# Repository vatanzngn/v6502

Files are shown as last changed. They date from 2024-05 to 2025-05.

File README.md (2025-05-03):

# 💻 vz6502: A Homebrew Single Board Computer Based on WDC 65C02

A custom-built single board computer (SBC) powered by the WDC 65C02 processor, featuring VGA and PS/2 interfaces, an onboard terminal, and a CPLD-based system controller.

---

## ⚙️ Specifications

- **CPU:** WDC 65C02 @ 1.8432 MHz (chosen for UART-compatible clock rate)
- **System Controller:** Altera EPM7128SLC84 CPLD
- **ROM:** Atmel 28C256 EEPROM (16 KB used)
- **RAM:** Hitachi 62256 SRAM (28 KB used)
- **Serial Interfaces:**  
  - 2× 65C51 ACIA (UART and terminal communication)
- **I/O Interface:**  
  - 1× 65C22 VIA
- **Video Output:** VGA interface  
- **Input:** PS/2 keyboard  
- **Terminal:** Atmega328P-based serial terminal

## 🧩 PCB Design

<div align="center">
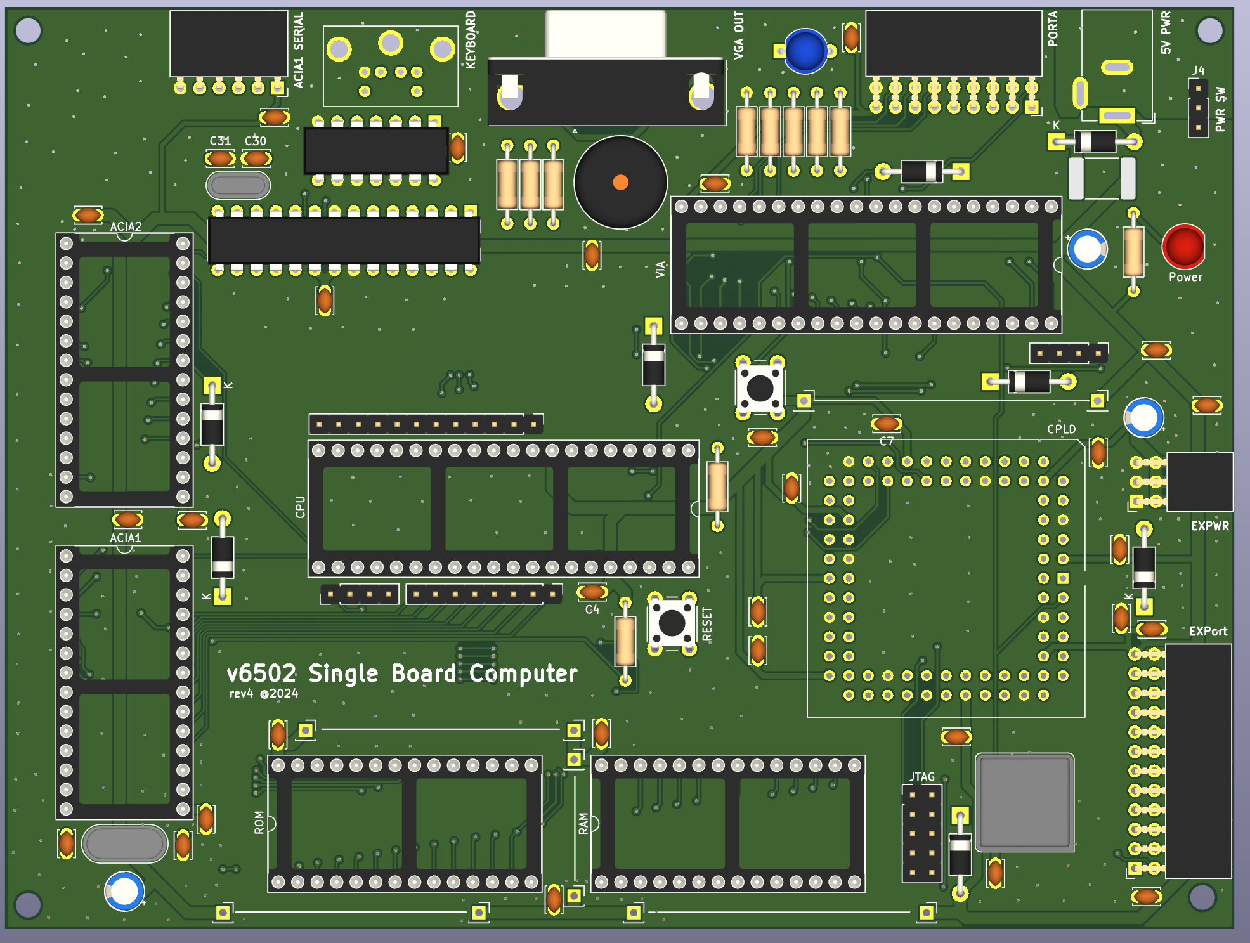
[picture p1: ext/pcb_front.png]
Front side of PCB
  
  <p><em>Front side of the PCB</em></p>
</div>

<div align="center">
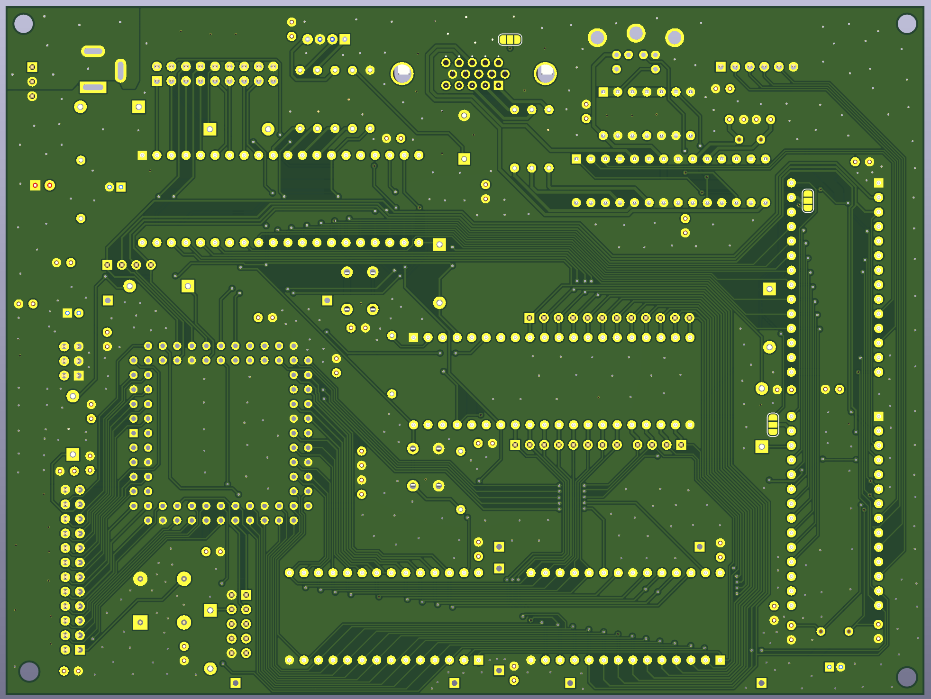
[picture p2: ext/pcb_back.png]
Back side of PCB
  
  <p><em>Back side of the PCB</em></p>
</div>

## 🔌 Schematic

<div align="center">
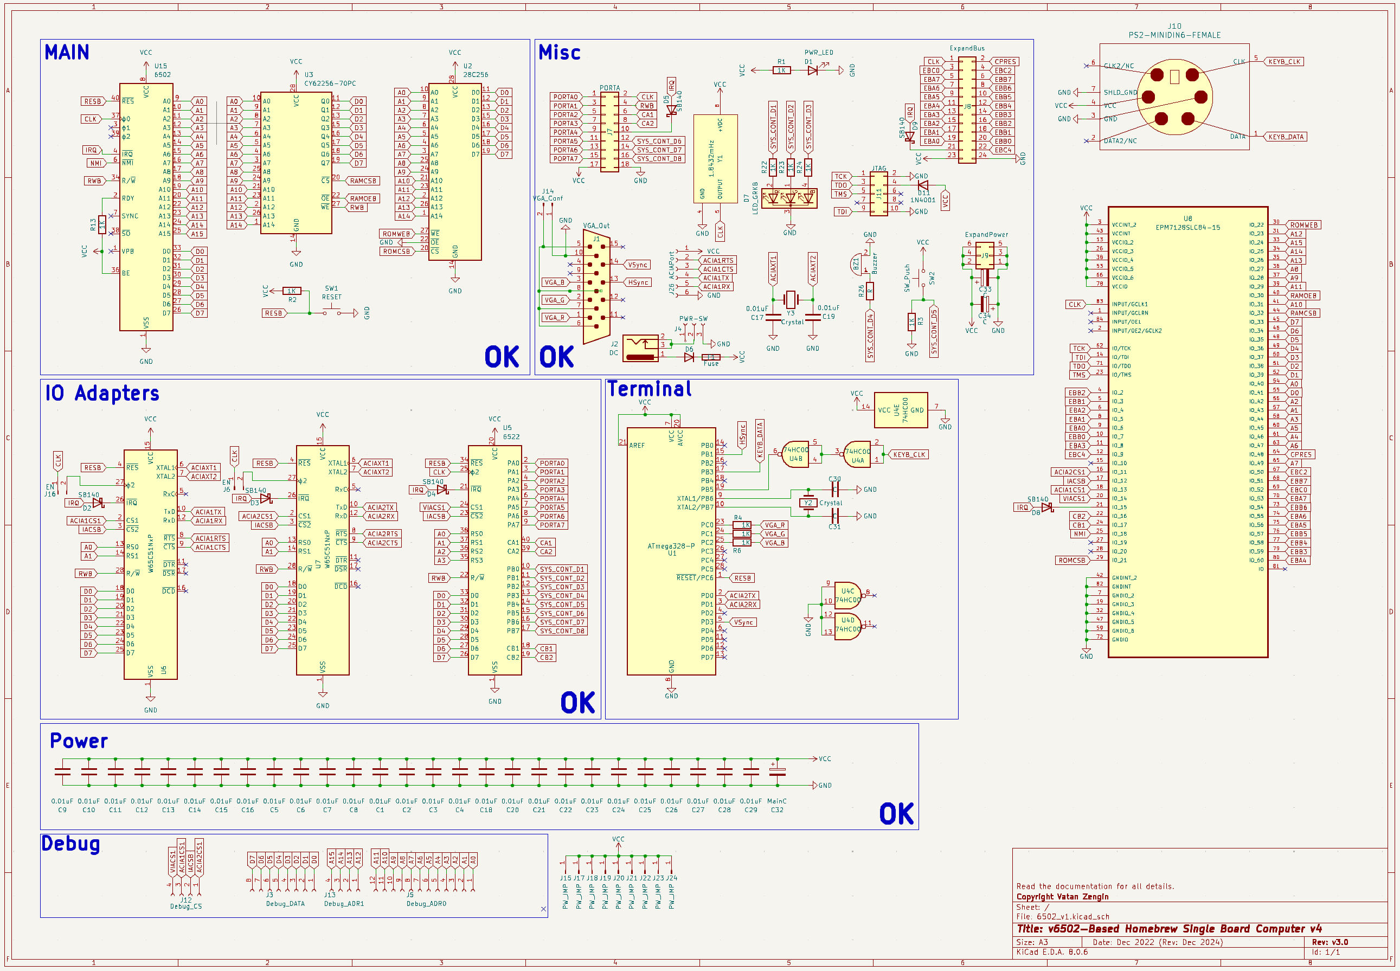
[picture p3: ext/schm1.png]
Schematic Diagram
  
  <p><em>System schematic showing CPU, RAM, ROM, I/O, and video interfaces</em></p>
</div>

## 🧠 Memory Map Overview

### 📋 Detailed Address Mapping

| Unit | First Address (bin) | Last Address (bin) | Address Range (Hex) | Description | Size  |
|---|---|---|---|---|---|
| RAM | 0000 0000 0000 0000 | 0110 1111 1111 1111 | 0000–6FFF | System memory | 28 KB |
| VIA0 | 0111 0000 0000 0000 | 0111 0000 0000 1100 | 7000–700C | VIA 0 registers | 12 B  |
| VIA1 | 0111 0001 0000 0000 | 0111 0001 0000 1100 | 7100–710C | VIA 1 registers | 12 B  |
| ACIA0  | 0111 0010 0000 0000 | 0111 0010 0000 0011 | 7200–7203 | ACIA 0 registers | 4 B |
| ACIA1  | 0111 0011 0000 0000 | 0111 0011 0000 0011 | 7300–7303 | ACIA 1 registers | 4 B |
| RESRV  | 0111 0100 0000 0000 | 0111 1111 1111 1111 | 7304–7FFF | Reserved | N/A |
| ROM | 1000 0000 0000 0000 | 1111 1111 1111 1111 | 8000–FFFF | System ROM | 32 KB |

---

## 📁 File Structure

| Folder | Description |
|---|---|
| `/pcb` | KiCAD PCB design files |
| `/gerber`| Gerber files for PCB manufacturing |
| `/ext` | GitHub assets, images, and extras  |

---
⚠️ CPLD and operating system source files will be uploaded in a future update.

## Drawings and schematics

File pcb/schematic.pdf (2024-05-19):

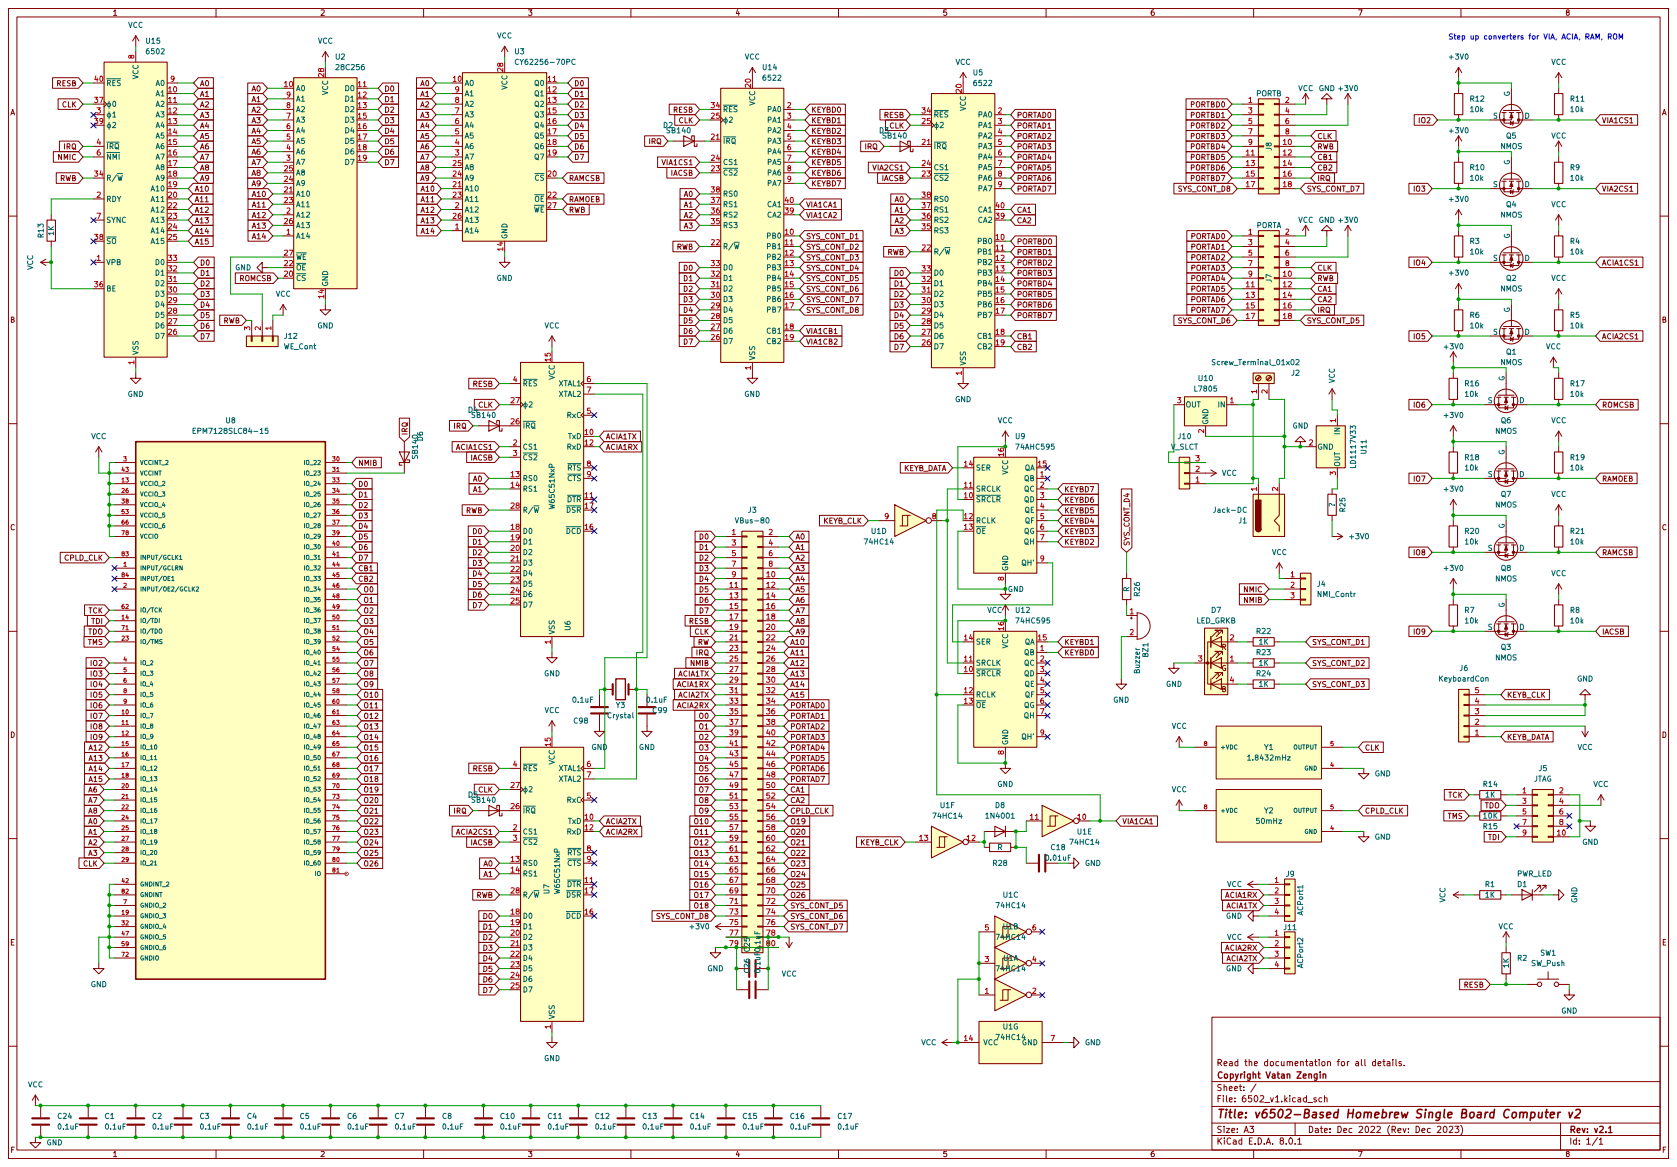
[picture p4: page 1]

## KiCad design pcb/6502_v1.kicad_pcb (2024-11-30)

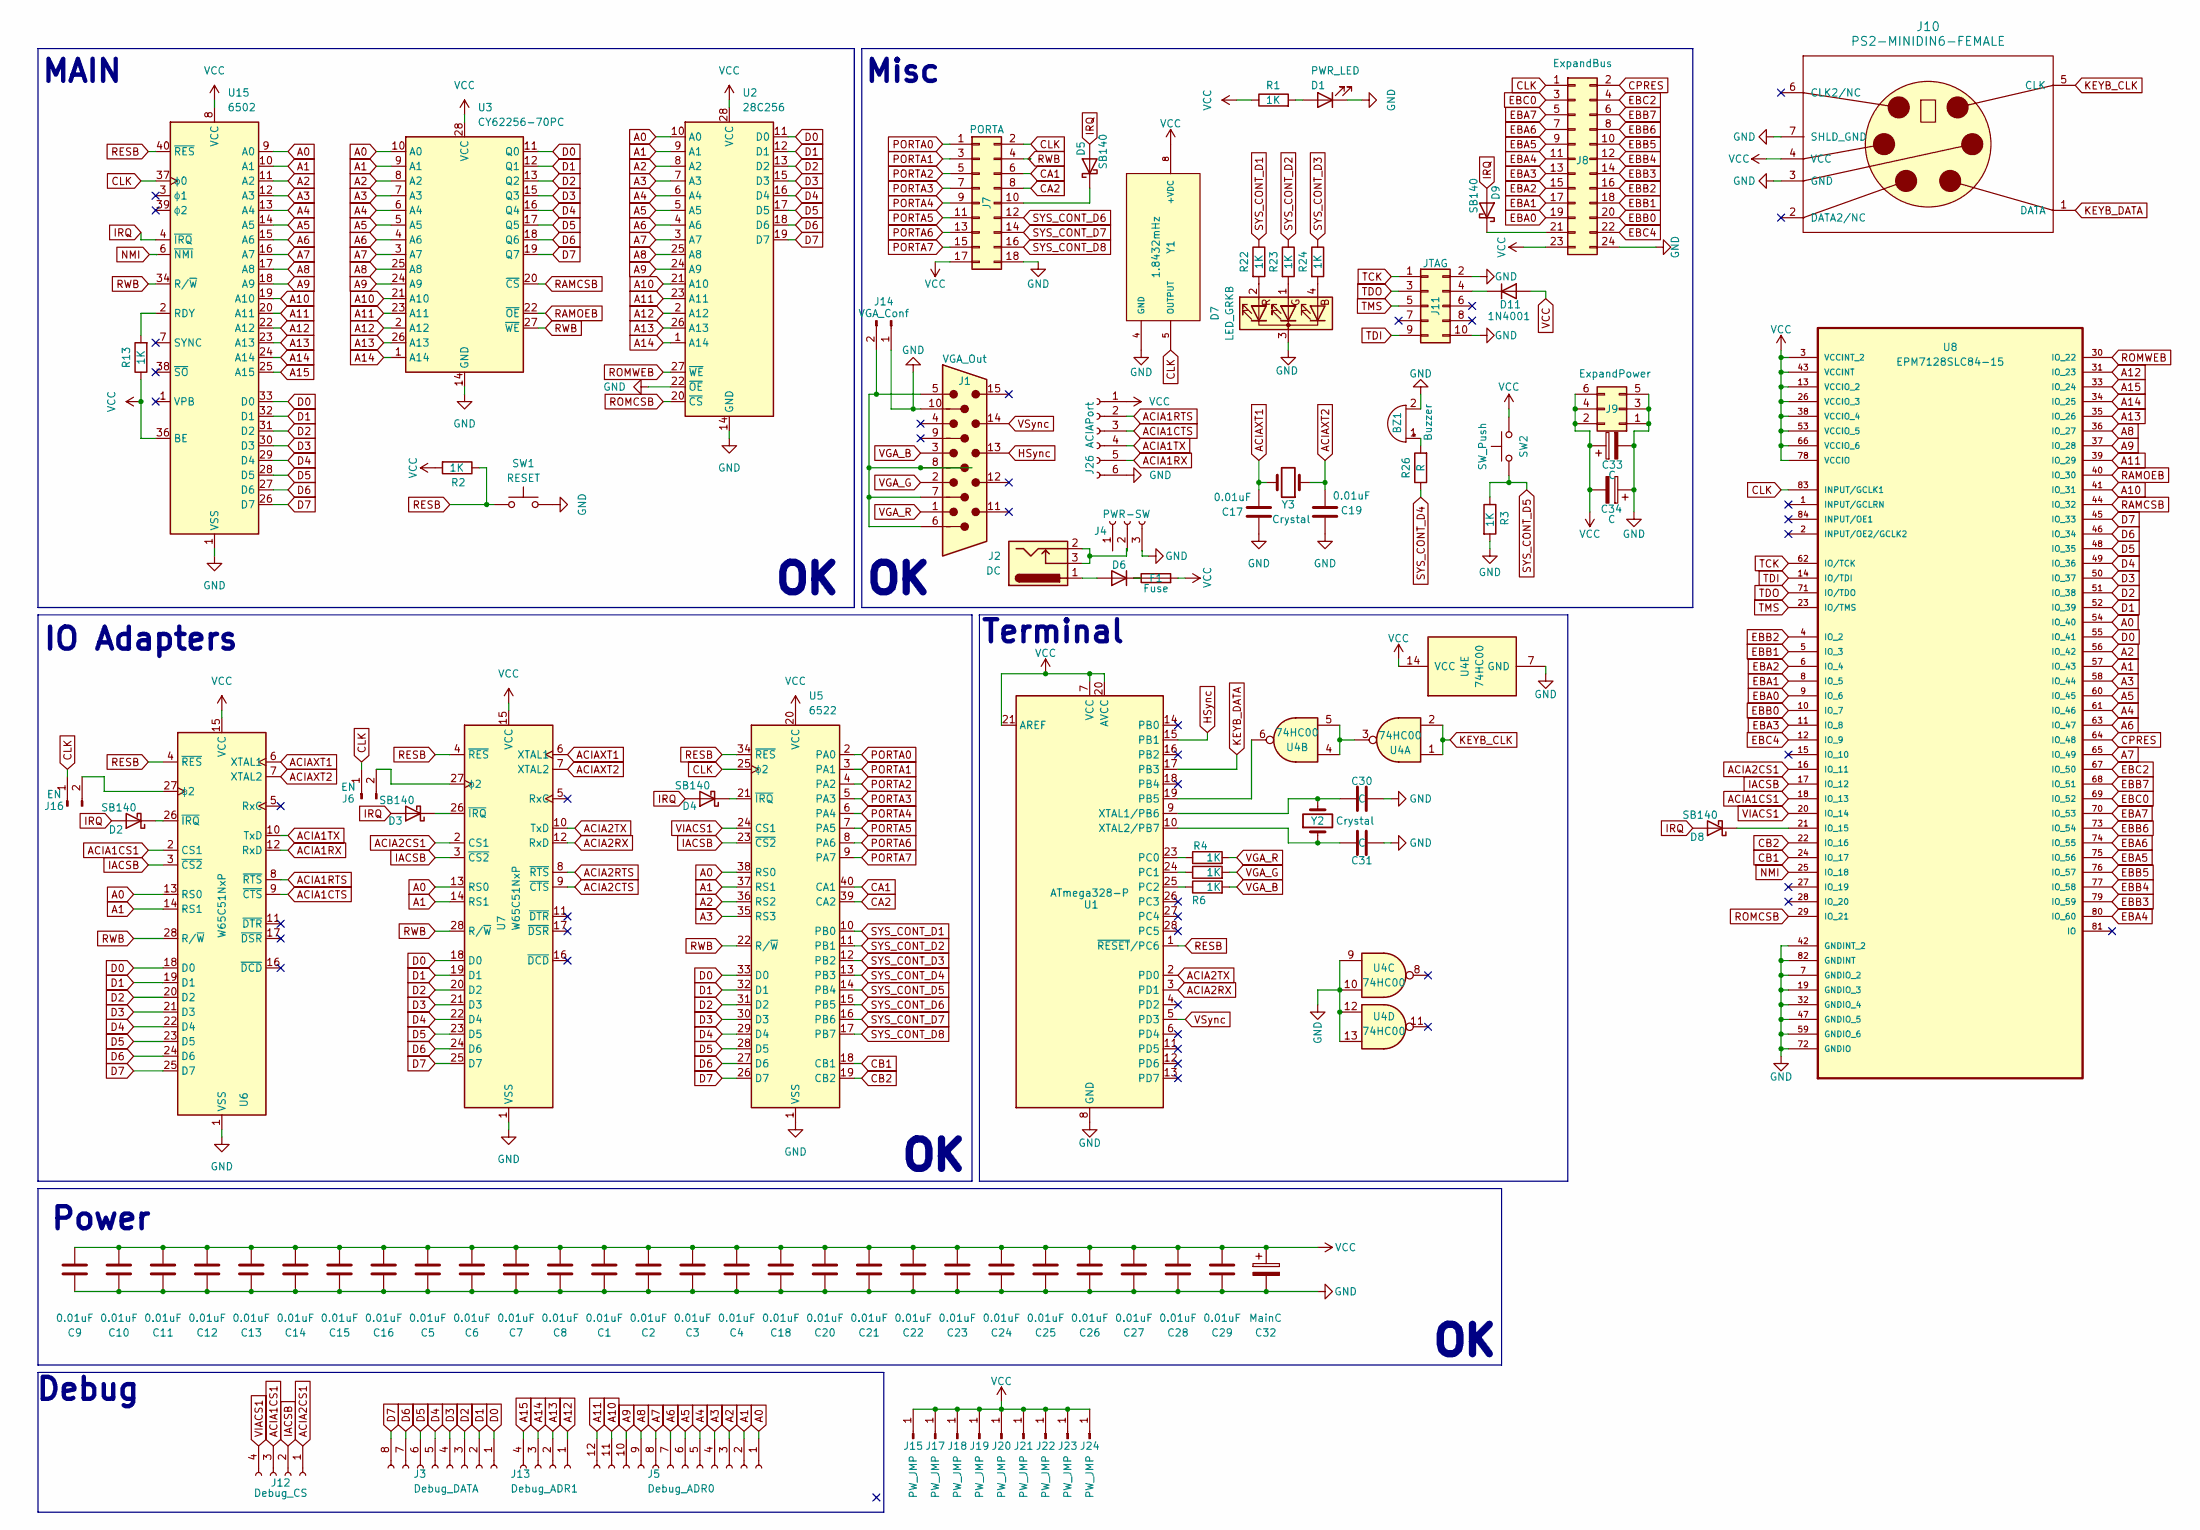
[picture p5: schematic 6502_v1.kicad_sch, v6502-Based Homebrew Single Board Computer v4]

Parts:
BZ1: Buzzer; Buzzer_12x9.5RM7.6
C1, C2, C3, C4, C5, C6, C7, C8, C9, C10, C11, C12, C13, C14, C15, C16, C17, C18, C19, C20, C21, C22, C23, C24, C25, C26, C27, C28, C29: 0.01uF; C_Disc_D3.4mm_W2.1mm_P2.50mm
C30, C31: C; C_Disc_D3.4mm_W2.1mm_P2.50mm
C32: MainC; CP_Radial_D5.0mm_P2.00mm
C33, C34: C; CP_Radial_D5.0mm_P2.00mm
D1: PWR_LED; LED_D5.0mm
D2, D3, D4, D5, D8, D9: SB140; D_DO-41_SOD81_P10.16mm_Horizontal
D6: D; D_DO-41_SOD81_P10.16mm_Horizontal
D7: LED_GRKB; LED_D5.0mm-4_RGB_Wide_Pins
D11: 1N4001; D_DO-41_SOD81_P10.16mm_Horizontal
F1: Fuse; Fuse_2920_7451Metric
J1: VGA_Out; DSUB-15-HD_Female_Horizontal_P2.29x1.98mm_EdgePinOffset3.03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
J2: DC; BarrelJack_GCT_DCJ200-10-A_Horizontal
J3: Debug_DATA; PinHeader_1x08_P2.54mm_Vertical
J4: PWR-SW; PinHeader_1x03_P2.54mm_Vertical
J5: Debug_ADR0; PinHeader_1x12_P2.54mm_Vertical
J6, J16: EN; SolderJumper-3_P1.3mm_Open_RoundedPad1.0x1.5mm_NumberLabels
J7: PORTA; PinSocket_2x09_P2.54mm_Horizontal
J8: ExpandBus; PinSocket_2x12_P2.54mm_Horizontal
J9: ExpandPower; PinSocket_2x03_P2.54mm_Horizontal
J10: PS2-MINIDIN6-FEMALE; MINI-DIN-6-FULL-SHIELD
J11: JTAG; PinHeader_2x05_P2.54mm_Vertical
J12: Debug_CS; PinHeader_1x04_P2.54mm_Vertical
J13: Debug_ADR1; PinHeader_1x04_P2.54mm_Vertical
J14: VGA_Conf; SolderJumper-3_P1.3mm_Open_RoundedPad1.0x1.5mm_NumberLabels
J15, J17, J18, J19, J20, J21, J22, J23, J24: PW_JMP; PinSocket_1x01_P2.54mm_Vertical
J26: ACIAPort; PinSocket_1x06_P2.54mm_Horizontal
R1, R2, R3, R4, R5, R6, R13, R22, R23, R24: 1K; R_Axial_DIN0207_L6.3mm_D2.5mm_P10.16mm_Horizontal
R26: R; R_Axial_DIN0207_L6.3mm_D2.5mm_P10.16mm_Horizontal
SW1: RESET; SW_PUSH_6mm_H4.3mm
SW2: SW_Push; SW_PUSH_6mm_H4.3mm
U1: ATmega328-P; DIP-28_W7.62mm
U2: 28C256; DIP-28_W15.24mm_Socket
U3: CY62256-70PC; DIP-28_W15.24mm_Socket
U4: 74HC00; DIP-14_W7.62mm
U5: 6522; DIP-40_W15.24mm_Socket
U6, U7: W65C51NxP; DIP-28_W15.24mm_Socket
U8: EPM7128SLC84-15; PLCC-84_THT-Socket; MPN EPM7128SLC84-15
U15: 6502; DIP-40_W15.24mm_Socket
Y1: 1.8432mHz; Oscillator_DIP-8_LargePads; PARTREV N/A
Y2: Crystal; Crystal_HC52-U_Vertical
Y3: Crystal; Crystal_HC18-U_Vertical

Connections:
A0: J5.1, U2.10 (A0), U3.10 (A0), U5.38 (RS0), U6.13 (RS0), U7.13 (RS0), U8.54 (IO_40), U15.9 (A0); also elsewhere on the board
A1: J5.2, U2.9 (A1), U3.9 (A1), U5.37 (RS1), U6.14 (RS1), U7.14 (RS1), U8.57 (IO_43), U15.10 (A1); also elsewhere on the board
A2: J5.3, U2.8 (A2), U3.8 (A2), U5.36 (RS2), U8.56 (IO_42), U15.11 (A2); also elsewhere on the board
A3: J5.4, U2.7 (A3), U3.7 (A3), U5.35 (RS3), U8.58 (IO_44), U15.12 (A3); also elsewhere on the board
A4: J5.5, U2.6 (A4), U3.6 (A4), U8.61 (IO_46), U15.13 (A4); also elsewhere on the board
A5: J5.6, U2.5 (A5), U3.5 (A5), U8.60 (IO_45), U15.14 (A5); also elsewhere on the board
A6: J5.7, U2.4 (A6), U3.4 (A6), U8.63 (IO_47), U15.15 (A6); also elsewhere on the board
A7: J5.8, U2.3 (A7), U3.3 (A7), U8.65 (IO_49), U15.16 (A7); also elsewhere on the board
A8: J5.9, U2.25 (A8), U3.25 (A8), U8.36 (IO_27), U15.17 (A8); also elsewhere on the board
A9: J5.10, U2.24 (A9), U3.24 (A9), U8.37 (IO_28), U15.18 (A9); also elsewhere on the board
A10: J5.11, U2.21 (A10), U3.21 (A10), U8.41 (IO_31), U15.19 (A10); also elsewhere on the board
A11: J5.12, U2.23 (A11), U3.23 (A11), U8.39 (IO_29), U15.20 (A11); also elsewhere on the board
A12: J13.1, U2.2 (A12), U3.2 (A12), U8.31 (IO_23), U15.22 (A12); also elsewhere on the board
A13: J13.2, U2.26 (A13), U3.26 (A13), U8.35 (IO_26), U15.23 (A13); also elsewhere on the board
A14: J13.3, U2.1 (A14), U3.1 (A14), U8.34 (IO_25), U15.24 (A14); also elsewhere on the board
A15: J13.4, U8.33 (IO_24), U15.25 (A15); also elsewhere on the board
ACIA1CS1: J12.3, U6.2 (CS1), U8.18 (IO_13); also elsewhere on the board
ACIA1CTS: J26.3, U6.9 (~CTS); also elsewhere on the board
ACIA1RTS: J26.2, U6.8 (~RTS); also elsewhere on the board
ACIA1RX: J26.5, U6.12 (RxD); also elsewhere on the board
ACIA1TX: J26.4, U6.10 (TxD); also elsewhere on the board
ACIA2CS1: J12.1, U7.2 (CS1), U8.16 (IO_11); also elsewhere on the board
ACIA2CTS: U7.9 (~CTS)
ACIA2RTS: U7.8 (~RTS)
ACIA2RX: U1.3 (PD1), U7.12 (RxD)
ACIA2TX: U1.2 (PD0), U7.10 (TxD)
ACIAXT1: C17.1, U6.6 (XTAL1), U7.6 (XTAL1), Y3.2; also elsewhere on the board
ACIAXT2: C19.1, U6.7 (XTAL2), U7.7 (XTAL2), Y3.1; also elsewhere on the board
CA1: J7.6, U5.40 (CA1)
CA2: J7.8, U5.39 (CA2)
CB1: U5.18 (CB1), U8.24 (IO_17); also elsewhere on the board
CB2: U5.19 (CB2), U8.22 (IO_16); also elsewhere on the board
CLK: J6.1, J7.2, J8.1, J16.1, U5.25 (ϕ2), U8.83 (INPUT/GCLK1), U15.37 (ϕ0), Y1.5 (OUTPUT); also elsewhere on the board
CPRES: J8.2, U8.64 (IO_48); also elsewhere on the board
D0: J3.1, U2.11 (D0), U3.11 (Q0), U5.33 (D0), U6.18 (D0), U7.18 (D0), U8.55 (IO_41), U15.33 (D0); also elsewhere on the board
D1: J3.2, U2.12 (D1), U3.12 (Q1), U5.32 (D1), U6.19 (D1), U7.19 (D1), U8.52 (IO_39), U15.32 (D1); also elsewhere on the board
D2: J3.3, U2.13 (D2), U3.13 (Q2), U5.31 (D2), U6.20 (D2), U7.20 (D2), U8.51 (IO_38), U15.31 (D2); also elsewhere on the board
D3: J3.4, U2.15 (D3), U3.15 (Q3), U5.30 (D3), U6.21 (D3), U7.21 (D3), U8.50 (IO_37), U15.30 (D3); also elsewhere on the board
D4: J3.5, U2.16 (D4), U3.16 (Q4), U5.29 (D4), U6.22 (D4), U7.22 (D4), U8.49 (IO_36), U15.29 (D4); also elsewhere on the board
D5: J3.6, U2.17 (D5), U3.17 (Q5), U5.28 (D5), U6.23 (D5), U7.23 (D5), U8.48 (IO_35), U15.28 (D5); also elsewhere on the board
D6: J3.7, U2.18 (D6), U3.18 (Q6), U5.27 (D6), U6.24 (D6), U7.24 (D6), U8.46 (IO_34), U15.27 (D6); also elsewhere on the board
D7: J3.8, U2.19 (D7), U3.19 (Q7), U5.26 (D7), U6.25 (D7), U7.25 (D7), U8.45 (IO_33), U15.26 (D7); also elsewhere on the board
EBA0: J8.19, U8.9 (IO_6); also elsewhere on the board
EBA1: J8.17, U8.8 (IO_5); also elsewhere on the board
EBA2: J8.15, U8.6 (IO_4); also elsewhere on the board
EBA3: J8.13, U8.11 (IO_8); also elsewhere on the board
EBA4: J8.11, U8.80 (IO_60); also elsewhere on the board
EBA5: J8.9, U8.75 (IO_56); also elsewhere on the board
EBA6: J8.7, U8.74 (IO_55); also elsewhere on the board
EBA7: J8.5, U8.70 (IO_53); also elsewhere on the board
EBB0: J8.20, U8.10 (IO_7); also elsewhere on the board
EBB1: J8.18, U8.5 (IO_3); also elsewhere on the board
EBB2: J8.16, U8.4 (IO_2); also elsewhere on the board
EBB3: J8.14, U8.79 (IO_59); also elsewhere on the board
EBB4: J8.12, U8.77 (IO_58); also elsewhere on the board
EBB5: J8.10, U8.76 (IO_57); also elsewhere on the board
EBB6: J8.8, U8.73 (IO_54); also elsewhere on the board
EBB7: J8.6, U8.68 (IO_51); also elsewhere on the board
EBC0: J8.3, U8.69 (IO_52); also elsewhere on the board
EBC2: J8.4, U8.67 (IO_50); also elsewhere on the board
EBC4: J8.22, U8.12 (IO_9); also elsewhere on the board
GND: BZ1.2 (+), C1.2, C2.2, C3.2, C4.2, C5.2, C6.2, C7.2, C8.2, C9.2, C10.2, C11.2, C12.2, C13.2, C14.2, C15.2, C16.2, C17.2, C18.2, C19.2, C20.2, C21.2, C22.2, C23.2, C24.2, C25.2, C26.2, C27.2, C28.2, C29.2, C30.2, C31.2, C32.2, C33.2, C34.1, D1.1 (K), D7.3 (K), J1.10, J4.3, J7.18, J8.24, J9.1, J9.3, J9.5, J10.3 (GND), J10.7 (SHLD_GND), J11.2, J11.10, J14.1, J26.6, R3.2, SW1.2, U1.8 (GND), U1.22 (GND), U2.14 (GND), U2.22 (~OE), U3.14 (GND), U4.7 (GND), U4.9, U4.10, U4.12, U4.13, U5.1 (VSS), U6.1 (VSS), U7.1 (VSS), U8.7 (GNDIO_2), U8.19 (GNDIO_3), U8.32 (GNDIO_4), U8.42 (GNDINT_2), U8.47 (GNDIO_5), U8.59 (GNDIO_6), U8.72 (GNDIO), U8.82 (GNDINT), U15.1 (VPB), U15.21 (VSS), Y1.4 (GND); also elsewhere on the board
HSync: J1.13, U1.15 (PB1)
IACSB: J12.2, U5.23 (~CS2), U6.3 (~CS2), U7.3 (~CS2), U8.17 (IO_12); also elsewhere on the board
IRQ: D2.2 (A), D3.2 (A), D4.2 (A), D5.2 (A), D8.2 (A), D9.2 (A), U15.4 (~IRQ); also elsewhere on the board
KEYB_CLK: J10.5 (CLK), U4.1, U4.2
KEYB_DATA: J10.1 (DATA), U1.17 (PB3)
unnamed: BZ1.1 (-), R26.2
unnamed 69: D1.2 (A), R1.2; also elsewhere on the board
unnamed 70: D2.1 (K), U6.26 (~IRQ); also elsewhere on the board
unnamed: D3.1 (K), U7.26 (~IRQ)
unnamed: D4.1 (K), U5.21 (~IRQ)
unnamed: D5.1 (K), J7.10
unnamed: D6.2 (A), J2.1
unnamed: D6.1 (K), F1.1
unnamed: D7.4 (BA), R24.2
unnamed: D7.1 (GA), R23.2
unnamed: D7.2 (RA), R22.2
unnamed 79: D8.1 (K), U8.21 (IO_15); also elsewhere on the board
unnamed: D9.1 (K), J8.21
unnamed 81: D11.1 (K), J11.4; also elsewhere on the board
unnamed: J2.2, J2.3, J4.2
unnamed: J6.2, U7.27 (ϕ2)
unnamed: J11.1, U8.62 (IO/TCK)
unnamed: J11.3, U8.71 (IO/TDO)
unnamed: J11.5, U8.23 (IO/TMS)
unnamed: J11.9, U8.14 (IO/TDI)
unnamed: J1.5, J1.6, J1.7, J1.8, J14.2
unnamed 89: J16.2, U6.27 (ϕ2); also elsewhere on the board
unnamed: U1.19 (PB5), U4.6
unnamed: R4.1, U1.23 (PC0)
unnamed: R5.1, U1.24 (PC1)
unnamed: R6.1, U1.25 (PC2)
unnamed: C30.1, U1.9 (XTAL1/PB6), Y2.2
unnamed: C31.1, U1.10 (XTAL2/PB7), Y2.1
unnamed: U2.20 (~CS), U8.29 (IO_21)
unnamed: U2.27 (~WE), U8.30 (IO_22)
unnamed: U3.20 (~CS), U8.44 (IO_32)
unnamed: U3.22 (~OE), U8.40 (IO_30)
unnamed: U4.3, U4.4, U4.5
unnamed: U8.25 (IO_18), U15.6 (~NMI)
unnamed 102: R13.2, U15.2 (RDY); also elsewhere on the board
PORTA0: J7.1, U5.2 (PA0)
PORTA1: J7.3, U5.3 (PA1)
PORTA2: J7.5, U5.4 (PA2)
PORTA3: J7.7, U5.5 (PA3)
PORTA4: J7.9, U5.6 (PA4)
PORTA5: J7.11, U5.7 (PA5)
PORTA6: J7.13, U5.8 (PA6)
PORTA7: J7.15, U5.9 (PA7)
RESB: R2.1, SW1.1, U1.1 (~RESET/PC6), U5.34 (~RES), U6.4 (~RES), U7.4 (~RES), U15.40 (~RES); also elsewhere on the board
RWB: J7.4, U3.27 (~WE), U5.22 (R/~W), U6.28 (R/~W), U7.28 (R/~W), U15.34 (R/~W); also elsewhere on the board
SYS_CONT_D1: R22.1, U5.10 (PB0)
SYS_CONT_D2: R23.1, U5.11 (PB1)
SYS_CONT_D3: R24.1, U5.12 (PB2)
SYS_CONT_D4: R26.1, U5.13 (PB3)
SYS_CONT_D5: R3.1, SW2.1, U5.14 (PB4)
SYS_CONT_D6: J7.12, U5.15 (PB5)
SYS_CONT_D7: J7.14, U5.16 (PB6)
SYS_CONT_D8: J7.16, U5.17 (PB7)
VCC: C1.1, C2.1, C3.1, C4.1, C5.1, C6.1, C7.1, C8.1, C9.1, C10.1, C11.1, C12.1, C13.1, C14.1, C15.1, C16.1, C18.1, C20.1, C21.1, C22.1, C23.1, C24.1, C25.1, C26.1, C27.1, C28.1, C29.1, C32.1, C33.1, C34.2, D11.2 (A), F1.2, J7.17, J8.23, J9.2, J9.4, J9.6, J10.4 (VCC), J15.1, J17.1, J18.1, J19.1, J20.1, J21.1, J22.1, J23.1, J24.1, J26.1, R1.1, R2.2, R13.1, SW2.2, U1.7 (VCC), U1.20 (AVCC), U1.21 (AREF), U2.28 (VCC), U3.28 (VCC), U4.14 (VCC), U5.20 (VCC), U6.15 (VCC), U7.15 (VCC), U8.3 (VCCINT_2), U8.13 (VCCIO_2), U8.26 (VCCIO_3), U8.38 (VCCIO_4), U8.43 (VCCINT), U8.53 (VCCIO_5), U8.66 (VCCIO_6), U8.78 (VCCIO), U15.8 (VCC), U15.36 (BE), Y1.8 (+VDC); also elsewhere on the board
VGA_B: J1.3, R6.2
VGA_G: J1.2, R5.2
VGA_R: J1.1, R4.2
VIACS1: J12.4, U5.24 (CS1), U8.20 (IO_14); also elsewhere on the board
VSync: J1.14, U1.5 (PD3)

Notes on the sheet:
Terminal
Power
MAIN
Debug
IO Adapters
Misc

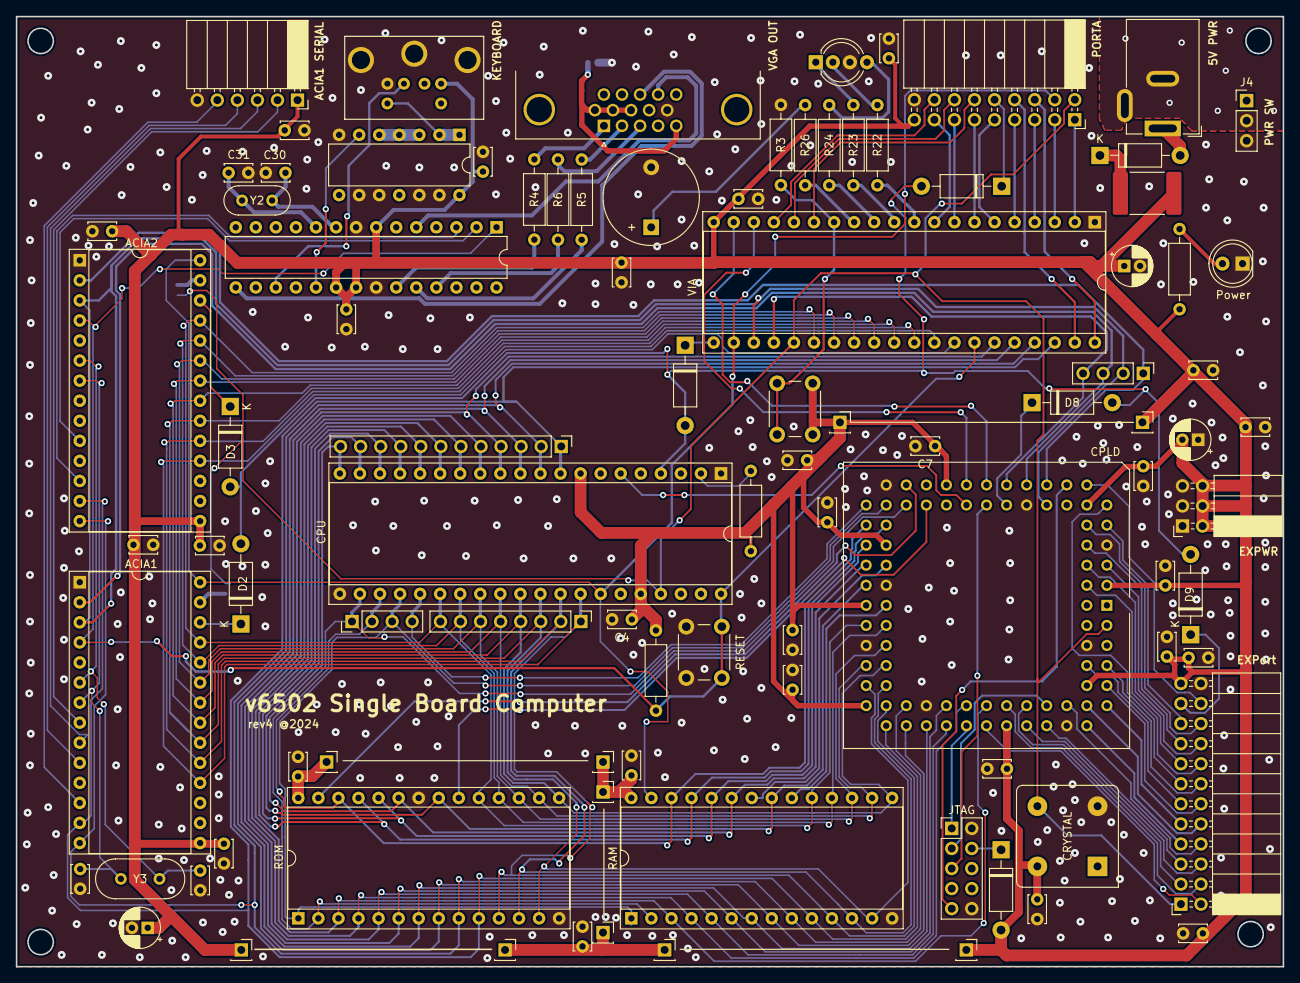
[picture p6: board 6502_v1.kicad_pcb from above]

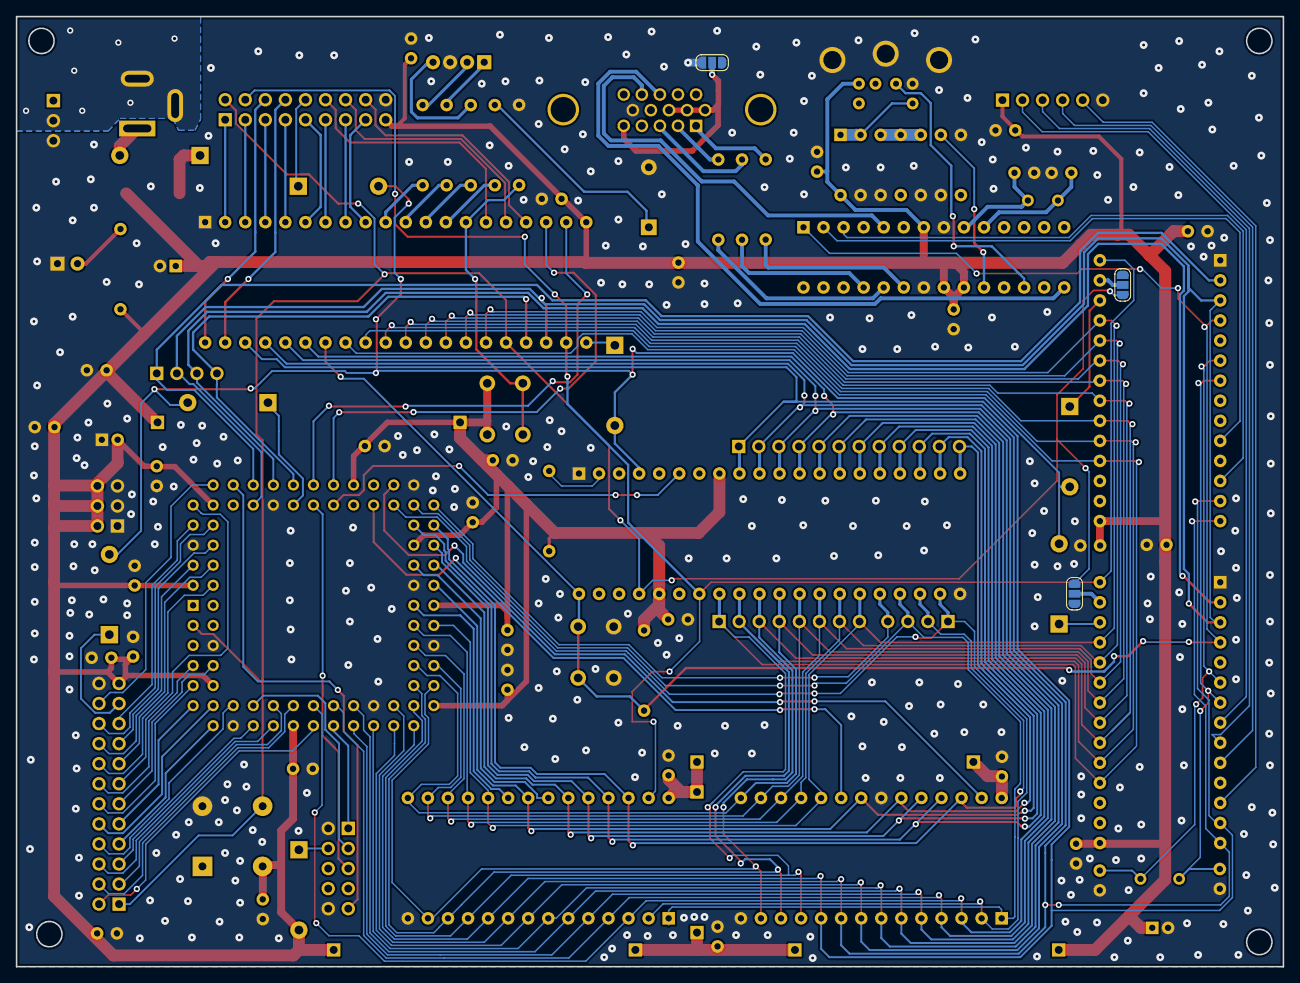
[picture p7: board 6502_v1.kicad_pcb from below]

Board: 2 copper layers, 160.4 x 120.3 mm, 98 parts (3 on the bottom side), 124 nets.

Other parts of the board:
ACIA1: W65C51NxP; DIP-28_W15.24mm_Socket
C2#2: 0.01uF; C_Disc_D3.4mm_W2.1mm_P2.50mm
CPLD: EPM7128SLC84-15; PLCC-84_THT-Socket
CPU: 6502; DIP-40_W15.24mm_Socket
CRYSTAL: 1.8432mHz; Oscillator_DIP-8_LargePads
J28: PW_JMP; PinSocket_1x01_P2.54mm_Vertical
JTAG: JTAG; PinHeader_2x05_P2.54mm_Vertical
Power: PWR_LED; LED_D5.0mm
RAM: CY62256-70PC; DIP-28_W15.24mm_Socket
RESET: RESET; SW_PUSH_6mm_H4.3mm
ROM: 28C256; DIP-28_W15.24mm_Socket

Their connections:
A0: ACIA1.13 (RS0), CPLD.54 (IO_40), CPU.9 (A0), RAM.10 (A0), ROM.10 (A0); also elsewhere on the board
A1: ACIA1.14 (RS1), CPLD.57 (IO_43), CPU.10 (A1), RAM.9 (A1), ROM.9 (A1); also elsewhere on the board
A2: CPLD.56 (IO_42), CPU.11 (A2), RAM.8 (A2), ROM.8 (A2); also elsewhere on the board
A3: CPLD.58 (IO_44), CPU.12 (A3), RAM.7 (A3), ROM.7 (A3); also elsewhere on the board
A4: CPLD.61 (IO_46), CPU.13 (A4), RAM.6 (A4), ROM.6 (A4); also elsewhere on the board
A5: CPLD.60 (IO_45), CPU.14 (A5), RAM.5 (A5), ROM.5 (A5); also elsewhere on the board
A6: CPLD.63 (IO_47), CPU.15 (A6), RAM.4 (A6), ROM.4 (A6); also elsewhere on the board
A7: CPLD.65 (IO_49), CPU.16 (A7), RAM.3 (A7), ROM.3 (A7); also elsewhere on the board
A8: CPLD.36 (IO_27), CPU.17 (A8), RAM.25 (A8), ROM.25 (A8); also elsewhere on the board
A9: CPLD.37 (IO_28), CPU.18 (A9), RAM.24 (A9), ROM.24 (A9); also elsewhere on the board
A10: CPLD.41 (IO_31), CPU.19 (A10), RAM.21 (A10), ROM.21 (A10); also elsewhere on the board
A11: CPLD.39 (IO_29), CPU.20 (A11), RAM.23 (A11), ROM.23 (A11); also elsewhere on the board
A12: CPLD.31 (IO_23), CPU.22 (A12), RAM.2 (A12), ROM.2 (A12); also elsewhere on the board
A13: CPLD.35 (IO_26), CPU.23 (A13), RAM.26 (A13), ROM.26 (A13); also elsewhere on the board
A14: CPLD.34 (IO_25), CPU.24 (A14), RAM.1 (A14), ROM.1 (A14); also elsewhere on the board
A15: CPLD.33 (IO_24), CPU.25 (A15); also elsewhere on the board
ACIA1CS1: ACIA1.2 (CS1), CPLD.18 (IO_13); also elsewhere on the board
ACIA1CTS: ACIA1.9 (~CTS); also elsewhere on the board
ACIA1RTS: ACIA1.8 (~RTS); also elsewhere on the board
ACIA1RX: ACIA1.12 (RxD); also elsewhere on the board
ACIA1TX: ACIA1.10 (TxD); also elsewhere on the board
ACIA2CS1: CPLD.16 (IO_11); also elsewhere on the board
ACIAXT1: ACIA1.6 (XTAL1); also elsewhere on the board
ACIAXT2: ACIA1.7 (XTAL2); also elsewhere on the board
CB1: CPLD.24 (IO_17); also elsewhere on the board
CB2: CPLD.22 (IO_16); also elsewhere on the board
CLK: CPLD.83 (INPUT/GCLK1), CPU.37 (ϕ0), CRYSTAL.5 (OUTPUT); also elsewhere on the board
CPRES: CPLD.64 (IO_48); also elsewhere on the board
D0: ACIA1.18 (D0), CPLD.55 (IO_41), CPU.33 (D0), RAM.11 (Q0), ROM.11 (D0); also elsewhere on the board
D1: ACIA1.19 (D1), CPLD.52 (IO_39), CPU.32 (D1), RAM.12 (Q1), ROM.12 (D1); also elsewhere on the board
D2: ACIA1.20 (D2), CPLD.51 (IO_38), CPU.31 (D2), RAM.13 (Q2), ROM.13 (D2); also elsewhere on the board
D3: ACIA1.21 (D3), CPLD.50 (IO_37), CPU.30 (D3), RAM.15 (Q3), ROM.15 (D3); also elsewhere on the board
D4: ACIA1.22 (D4), CPLD.49 (IO_36), CPU.29 (D4), RAM.16 (Q4), ROM.16 (D4); also elsewhere on the board
D5: ACIA1.23 (D5), CPLD.48 (IO_35), CPU.28 (D5), RAM.17 (Q5), ROM.17 (D5); also elsewhere on the board
D6: ACIA1.24 (D6), CPLD.46 (IO_34), CPU.27 (D6), RAM.18 (Q6), ROM.18 (D6); also elsewhere on the board
D7: ACIA1.25 (D7), CPLD.45 (IO_33), CPU.26 (D7), RAM.19 (Q7), ROM.19 (D7); also elsewhere on the board
EBA0: CPLD.9 (IO_6); also elsewhere on the board
EBA1: CPLD.8 (IO_5); also elsewhere on the board
EBA2: CPLD.6 (IO_4); also elsewhere on the board
EBA3: CPLD.11 (IO_8); also elsewhere on the board
EBA4: CPLD.80 (IO_60); also elsewhere on the board
EBA5: CPLD.75 (IO_56); also elsewhere on the board
EBA6: CPLD.74 (IO_55); also elsewhere on the board
EBA7: CPLD.70 (IO_53); also elsewhere on the board
EBB0: CPLD.10 (IO_7); also elsewhere on the board
EBB1: CPLD.5 (IO_3); also elsewhere on the board
EBB2: CPLD.4 (IO_2); also elsewhere on the board
EBB3: CPLD.79 (IO_59); also elsewhere on the board
EBB4: CPLD.77 (IO_58); also elsewhere on the board
EBB5: CPLD.76 (IO_57); also elsewhere on the board
EBB6: CPLD.73 (IO_54); also elsewhere on the board
EBB7: CPLD.68 (IO_51); also elsewhere on the board
EBC0: CPLD.69 (IO_52); also elsewhere on the board
EBC2: CPLD.67 (IO_50); also elsewhere on the board
EBC4: CPLD.12 (IO_9); also elsewhere on the board
GND: ACIA1.1 (VSS), C2#2.2, CPLD.7 (GNDIO_2), CPLD.19 (GNDIO_3), CPLD.32 (GNDIO_4), CPLD.42 (GNDINT_2), CPLD.47 (GNDIO_5), CPLD.59 (GNDIO_6), CPLD.72 (GNDIO), CPLD.82 (GNDINT), CPU.1 (VSS), CPU.21 (VSS), CRYSTAL.4 (GND), JTAG.2, JTAG.10, Power.1 (K), RAM.14 (GND), RESET.2, ROM.14 (GND), ROM.22 (~OE); also elsewhere on the board
IACSB: ACIA1.3 (~CS2), CPLD.17 (IO_12); also elsewhere on the board
IRQ: CPU.4 (~IRQ); also elsewhere on the board
NMI: CPLD.25 (IO_18), CPU.6 (~NMI)
unnamed 69: Power.2 (A); also elsewhere on the board
unnamed 70: ACIA1.26 (~IRQ); also elsewhere on the board
unnamed 79: CPLD.21 (IO_15); also elsewhere on the board
unnamed 81: JTAG.4; also elsewhere on the board
unnamed 89: ACIA1.27 (ϕ2); also elsewhere on the board
unnamed 102: CPU.2 (RDY); also elsewhere on the board
RAMCSB: CPLD.44 (IO_32), RAM.20 (~CS)
RAMOEB: CPLD.40 (IO_30), RAM.22 (~OE)
RESB: ACIA1.4 (~RES), CPU.40 (~RES), RESET.1; also elsewhere on the board
ROMCSB: CPLD.29 (IO_21), ROM.20 (~CS)
ROMWEB: CPLD.30 (IO_22), ROM.27 (~WE)
RWB: ACIA1.28 (R/~W), CPU.34 (R/~W), RAM.27 (~WE); also elsewhere on the board
TCK: CPLD.62 (IO/TCK), JTAG.1
TDI: CPLD.14 (IO/TDI), JTAG.9
TDO: CPLD.71 (IO/TDO), JTAG.3
TMS: CPLD.23 (IO/TMS), JTAG.5
VCC: ACIA1.15 (VCC), C2#2.1, CPLD.3 (VCCINT_2), CPLD.13 (VCCIO_2), CPLD.26 (VCCIO_3), CPLD.38 (VCCIO_4), CPLD.43 (VCCINT), CPLD.53 (VCCIO_5), CPLD.66 (VCCIO_6), CPLD.78 (VCCIO), CPU.8 (VCC), CPU.36 (BE), CRYSTAL.8 (+VDC), J28.1, RAM.28 (VCC), ROM.28 (VCC); also elsewhere on the board
VIACS1: CPLD.20 (IO_14); also elsewhere on the board

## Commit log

2024-05-19 Upload PCB Files.
    [6502_v1.kicad_pcb, 6502_v1.kicad_sch]
2024-11-30 V4 Pcb Upload.
    [6502_v1.kicad_pcb, 6502_v1.kicad_sch]
2024-11-30 v4 Gerber File Upload
    [6502_v1-B_Cu.gbl, 6502_v1-B_Mask.gbs, 6502_v1-B_Paste.gbp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]
2024-12-01 Silkscreen Update
    [6502_v1-B_Cu.gbl, 6502_v1-B_Mask.gbs, 6502_v1-B_Paste.gbp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]

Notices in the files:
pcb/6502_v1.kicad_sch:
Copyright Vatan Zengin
